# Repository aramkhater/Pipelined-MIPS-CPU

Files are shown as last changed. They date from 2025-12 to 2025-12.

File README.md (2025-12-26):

# Pipelined MIPS CPU 

## Overview

This project is a VHDL implementation of a **32-bit Pipelined MIPS CPU** architecture. It aims to create a high-performance processor that executes instructions through five pipeline stages—**IF, ID, EX, MEM, and WB**—to optimize instruction throughput. The system includes robust logic for **Forwarding** and **Data Hazard Detection** to handle dependencies and control flow changes in real hardware.

---

## Table of Contents

* [System Design](#system-design)
* [Control Unit](#control-unit)
* [Data Path & Pipeline Stages](#data-path--pipeline-stages)
* [Hazard Management](#hazard-management)
* [Verification & Performance](#verification--performance)

---

## System Design

The design encapsulates all necessary modules for pipelined MIPS operation, integrating memory components and specialized hazard units.

### File Descriptions

**`aux_package.vhd`**
* Defines all component declarations, enabling interconnections between the various stages and control modules.

**`MIPS.vhd`**
* Serves as the top-level structural model, integrating all pipeline stages and the hazard/forwarding units.
* **Inputs/Outputs:**
    * Reset and clock inputs, including PLL integration for hardware deployment.
    * `BPADDR_i` for hardware breakpoint support.
    * Performance counters: `mclk_cnt_o` (clock cycles), `inst_cnt_o` (instructions), and `STCNT_o` (stalls).

**`IFETCH.VHD`**
* Manages the Program Counter (PC) and retrieves instructions from the Instruction TCM (ITCM).
* Supports PC increments, branch targets, and jump addresses while allowing for pipeline stalls via `pc_write_i`.

**`IDECODE.VHD`**
* Implements the Register File consisting of 32 registers of 32-bit width.
* Decodes instructions, performs sign-extension, and handles branch condition evaluation at the ID stage to reduce branch penalties.

**`EXECUTE.VHDL`**
* Performs arithmetic and logical operations using the ALU.
* Handles operand selection from the Register File or forwarded data from MEM/WB stages.

**`DMEMORY.VHD`**
* Implements the Data TCM (DTCM) for load and store operations.
* Interfaces with the pipeline to read data for `lw` or write data for `sw` instructions.

**`WB.vhd`**
* The Write Back stage, which selects between the ALU result and memory data to be written back to the Register File.

---

## Control Unit

**`CONTROL.VHD`**
* Implements the main combinatorial control logic.
* Generates signals such as `RegWrite`, `MemtoReg`, `ALUSrc`, and `Branch` based on the 6-bit opcode and function code.
* Supports R-type, I-type (e.g., `addi`, `lw`), and J-type (e.g., `jmp`, `jal`, `jr`) instructions.

---

## Data Path & Pipeline Stages

The datapath is divided into registers that coordinate data flow between cycles:
* **`IF_ID.vhd`**: Captures fetched instructions and $PC+4$.
* **`ID_EX.vhd`**: Passes decoded register values, control signals, and immediates to the execution stage.
* **`EX_MEM.vhd`**: Carries ALU results and store data to the memory stage.
* **`MEM_WB.vhd`**: Routes memory data or ALU results to the final write-back logic.

---

## Hazard Management

This processor includes dedicated hardware to resolve dependencies that arise in pipelined architectures:

**`Forwarding_Unit.vhd`**
* Resolves data hazards by routing data directly from the EX/MEM or MEM/WB stages back to the ALU inputs.
* Improves performance by allowing the CPU to use a result before it is officially written to the Register File.

**`Datahazard_Unit.vhd`**
* Detects Load-Use hazards where an instruction requires data immediately after a `lw` instruction.
* Stalls the pipeline by disabling PC and IF/ID updates and inserting a "nope" (no-op) into control signals.
* Manages Control Hazards by flushing the pipeline (clearing IF/ID) when a branch or jump is taken.

---

## Verification & Performance

The system was verified through a comprehensive process:
* **ModelSim Simulation:** Functional correctness was tested using a Matrix Addition program. Waveforms verified correct forwarding, stall insertion on hazards, and flush behavior.
* **Hardware Validation:** The design was synthesized using Quartus and deployed on a DE10-Standard FPGA.
* **SignalTap Analysis:** Real-time execution was captured to confirm instruction flow and breakpoint triggers at address `0x030`.
* **Performance Results:** The Matrix Addition test achieved an **IPC of 0.83** with a restricted $F_{max}$ for the system clock of **32.79 MHz**.

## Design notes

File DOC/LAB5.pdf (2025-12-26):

## Pipelined MIPS CPU on FPGA – Design and

## Verification Report

## ADVANCED CPU ARCHITECTURE AND HARDWARE

## ACCELERATORS LAB

361.1.4693

## Ahseen Alazazma 324038132

## Aram Khater 314813452

### 1. LAB overview:

In this lab, we implemented a pipelined MIPS CPU architecture supporting full data

hazard detection and forwarding mechanisms. The design includes all five standard

pipeline stages — IF, ID, EX, MEM, and WB — with additional logic to handle stalls,

flushes, and control flow changes.

The CPU was first verified using ModelSim through the simulation of a custom hand-

written assembly program, ensuring functional correctness and proper pipeline behavior.

After successful simulation, the design was synthesized using Quartus and deployed on

an FPGA. Final validation was performed using SignalTap to capture and inspect live

execution, confirming correct memory access, instruction sequencing, and pipeline

control under real hardware conditions.

### 2. Test program

To evaluate the functionality of our MIPS CPU, we ran several test programs covering

arithmetic operations, memory access (load/store), branches, and jumps. One

representative example is a matrix addition program written in C and compiled to MIPS

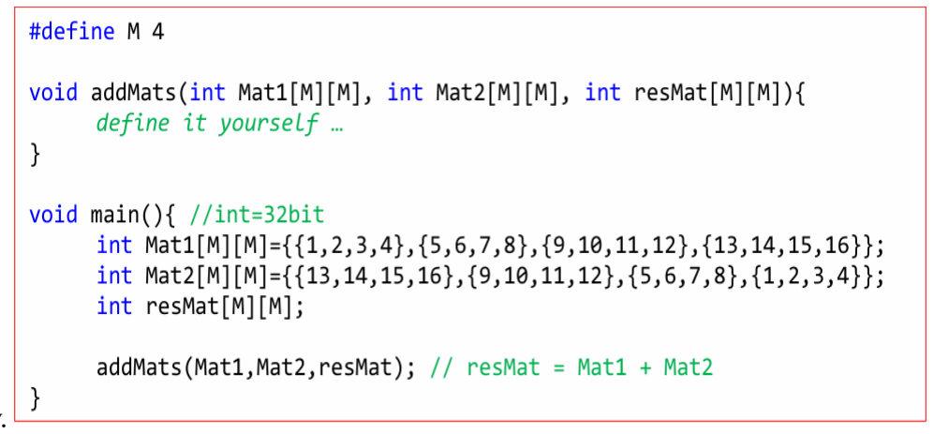
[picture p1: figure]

assembly.

Figure 1: C program for adding two matrices

And it’s version in assembly:

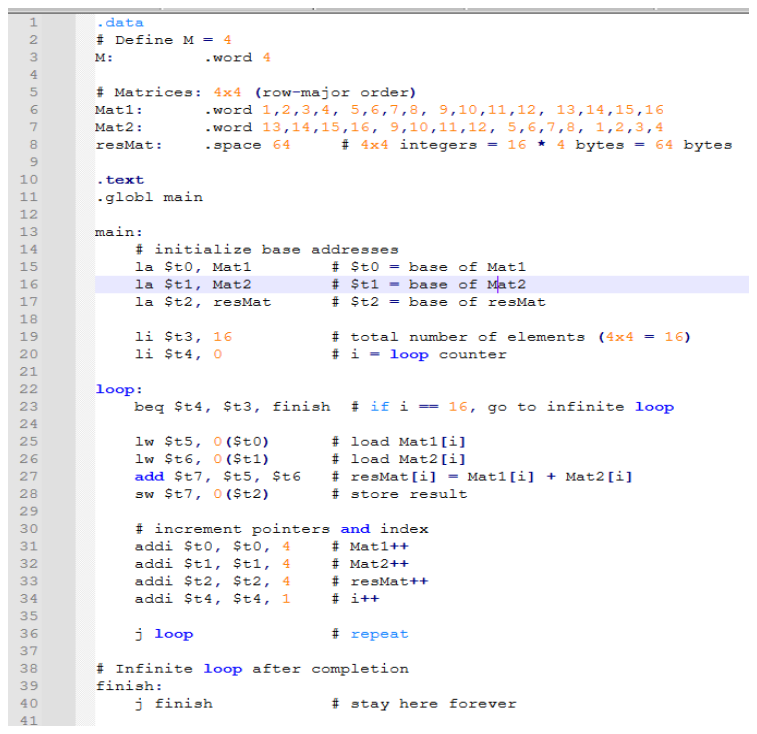
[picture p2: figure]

Figure 2: assembly program

### 3. Simulation Verification (ModelSim)

ModelSim simulation confirmed correct instruction sequencing and data propagation through the pipeline stages. We used waveform inspection to verify:

- Proper forwarding of values (e.g., add after lw)
- Correct stall insertion on load-use hazards
- Accurate memory writes at the correct cycle
- Instruction alignment across pipeline registers

The following show how the data flow in pipeline:

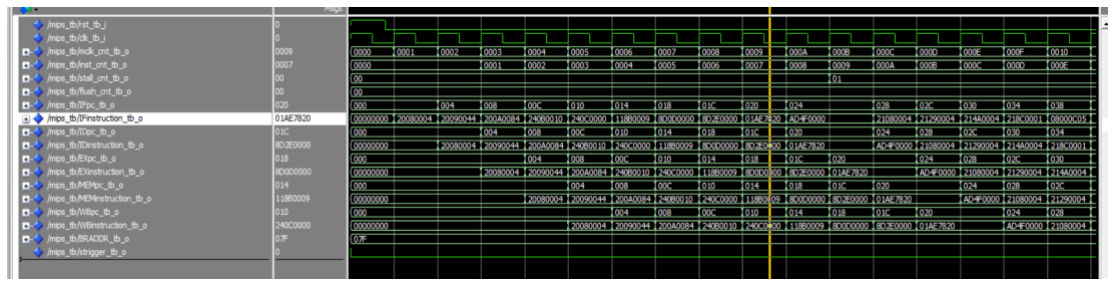
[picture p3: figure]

Figure 3: Pipeline flow

The following show correct handling when the branch taken the next fetched instruction is flushed and the flush counter increased by 1:

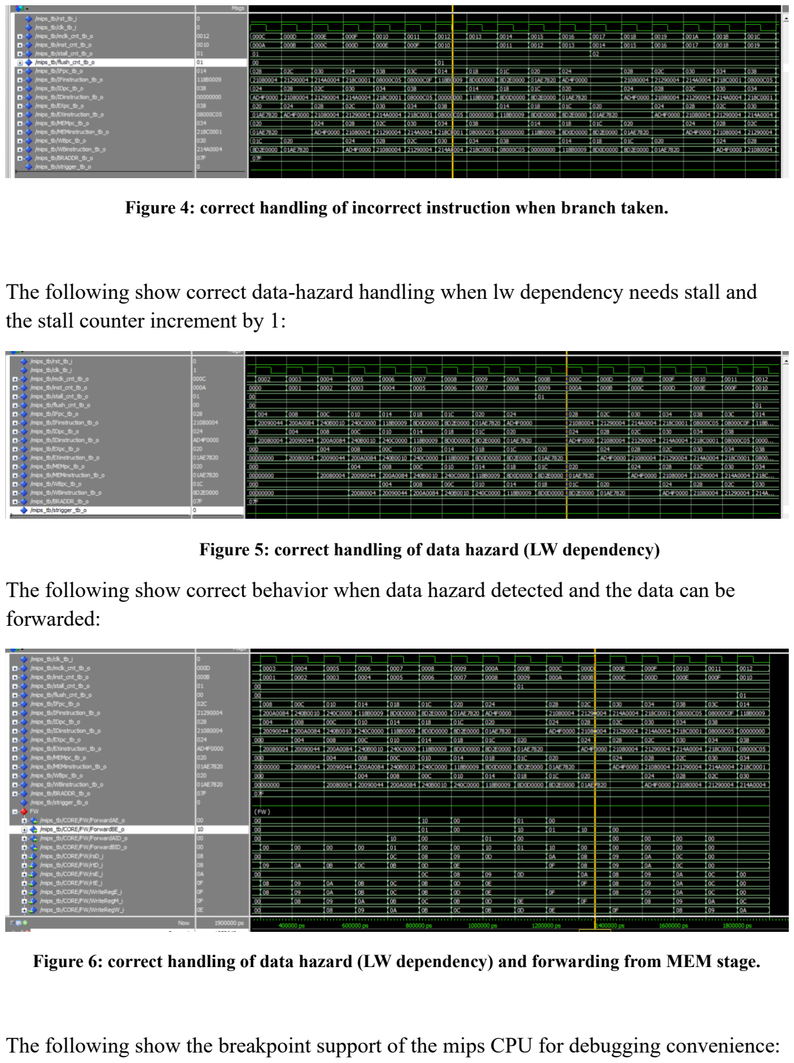
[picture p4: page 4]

Figure 4: correct handling of incorrect instruction when branch taken.

The following show correct data-hazard handling when lw dependency needs stall and the stall counter increment by 1:

Figure 5: correct handling of data hazard (LW dependency)

The following show correct behavior when data hazard detected and the data can be forwarded:

Figure 6: correct handling of data hazard (LW dependency) and forwarding from MEM stage.

The following show the breakpoint support of the mips CPU for debugging convenience:

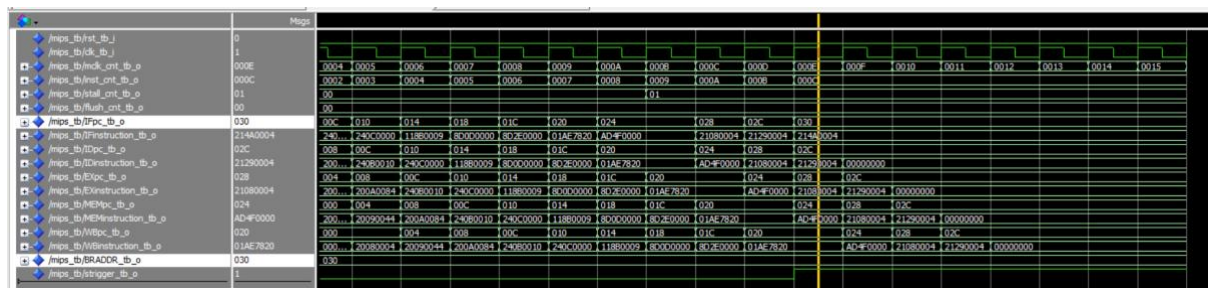
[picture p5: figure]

Figure 7: breakpoint support

The following show the content data memory after completing the program, which match the theoretical behavior:

Figure 8: Data memory content (the matrices and the summed matrix)

### 4. Hardware Validation (Quartus + SignalTap)

After ModelSim verification, the CPU was synthesized and deployed on the FPGA.

Using SignalTap, we validated:

- Live instruction flow across pipeline stages
- Real-time stalls and flushes
- Breakpoint detection
- Output memory content

The contents of memory after execution were compared between Quartus and ModelSim and matched, confirming consistent behavior between simulation and hardware.

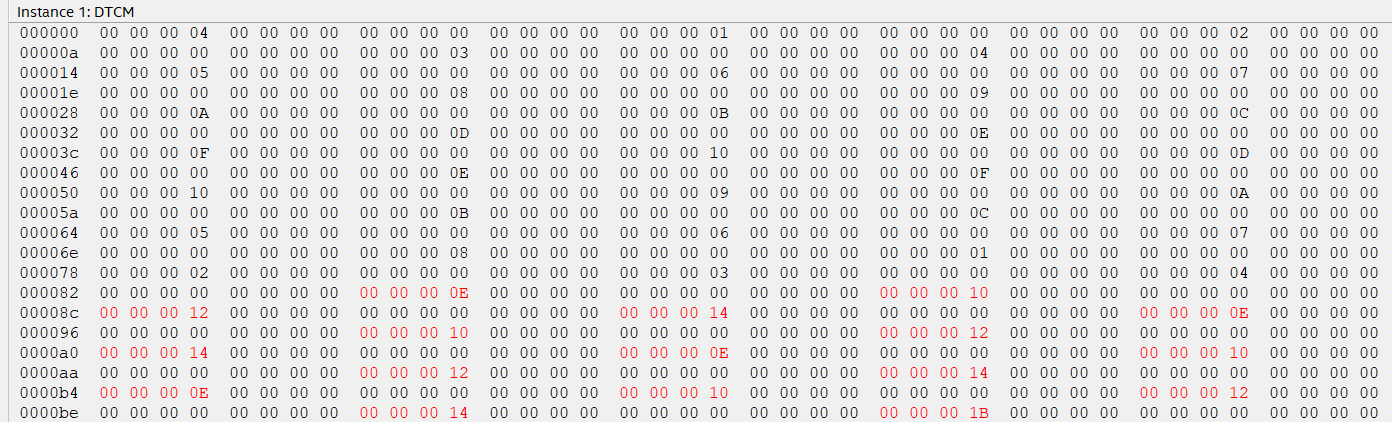
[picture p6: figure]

Figure 9: Quartus memory content

To validate runtime control, a breakpoint mechanism was implemented. Figure 9 shows a capture in SignalTap where execution halts when the PC reaches address 0x030, as expected.

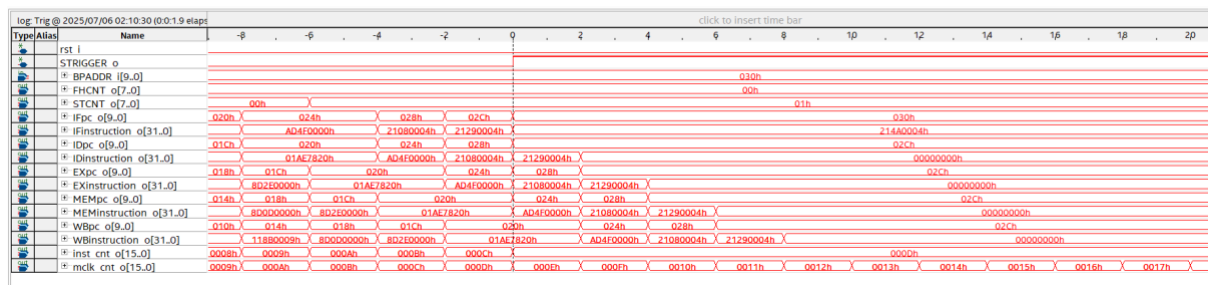
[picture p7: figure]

Figure 10: SignalTap breakpoint at PC=0x30

This confirms correct operation of the breakpoint detection and integration with pipeline control.

The following show correct stalling after data hazard detected and stall counter incremented by 1:

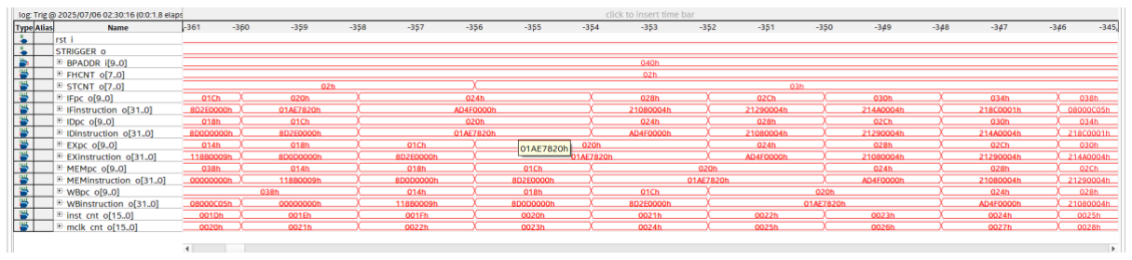
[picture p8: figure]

Figure 11: SignalTap, stall after data dependency.

The following show correct stalling after wrong instruction detected (branch taken) and flush counter incremented by 1:

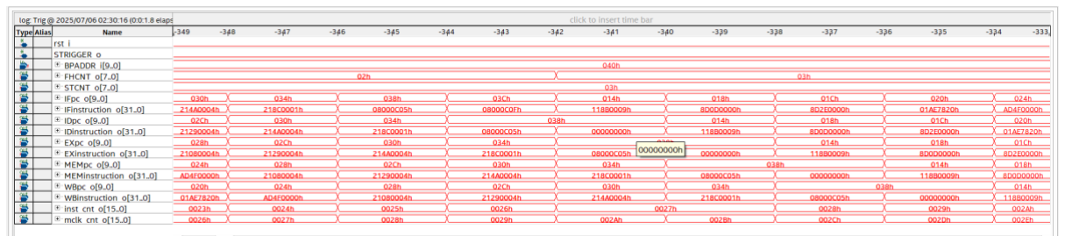
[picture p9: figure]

Figure 12: SignalTap, flush after branch taken.

### 5. Comparison

As shown in Figures X and Y, the data memory after execution is consistent between simulation (ModelSim) and real hardware (Quartus). This validates that memory control logic, address calculation, and write-back stages behave identically.

### 6. IPC calculation

The execution of the program took 199 clock cycle, 181 instructions, 16 stalls and 16 flush.

We can calculate the IPC using the following equation:

Using the clock cycle counter and instruction counter on FPGA, we calculated the IPC (Instructions Per Cycle) of the matrix addition program to be approximately 0.83. This accounts for stalls due to load-use hazards and control flow changes like branches.

### 7. critical path and maximum clock for pipelined mips

Following the maximum clock speed for the pipelined mips:

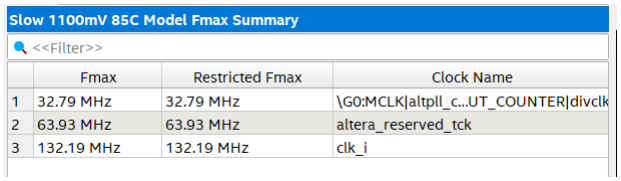
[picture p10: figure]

Figure 13: Maximum clock speed of the pipelined mips

The following show the critical path of the pipelined mips CPU:

Figure 14: critical path of the pipelined mips.

### 8. critical path and maximum clock for pipeline mips

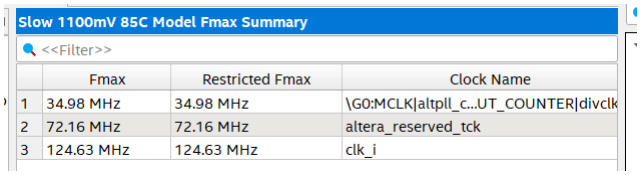
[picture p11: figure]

Figure 15: Maximum clock speed of the single cycle mips.

Figure 16: critical path of the single cycle mips.

### 9. RTL

MIPS Pipeline Processor RTL

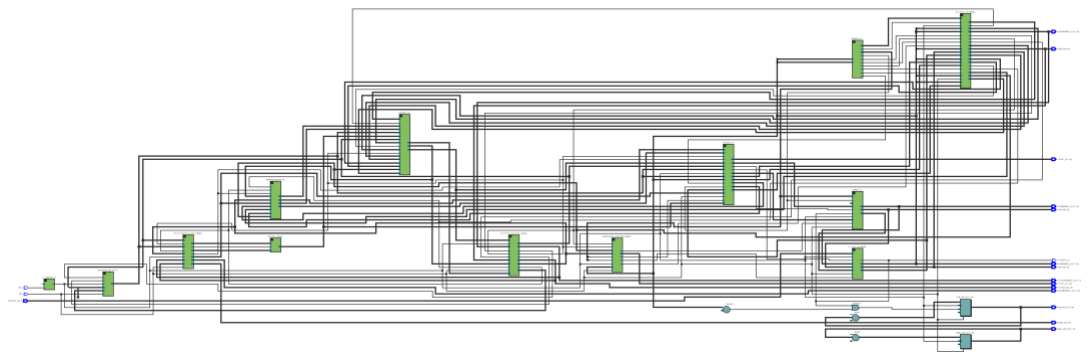
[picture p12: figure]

Instruction Fetch

Instruction Fetch (IF) stage is responsible for retrieving the next instruction to be executed. It reads the current value of the Program Counter (PC), uses it to access the instruction memory, fetches the instruction located at that address, and calculates the address of the next instruction by adding 4 to the PC. The fetched instruction and the incremented PC (PC + 4) are then passed to the next pipeline stage (Instruction Decode), while the PC is updated to point to the next instruction, unless a branch or jump alters the flow.

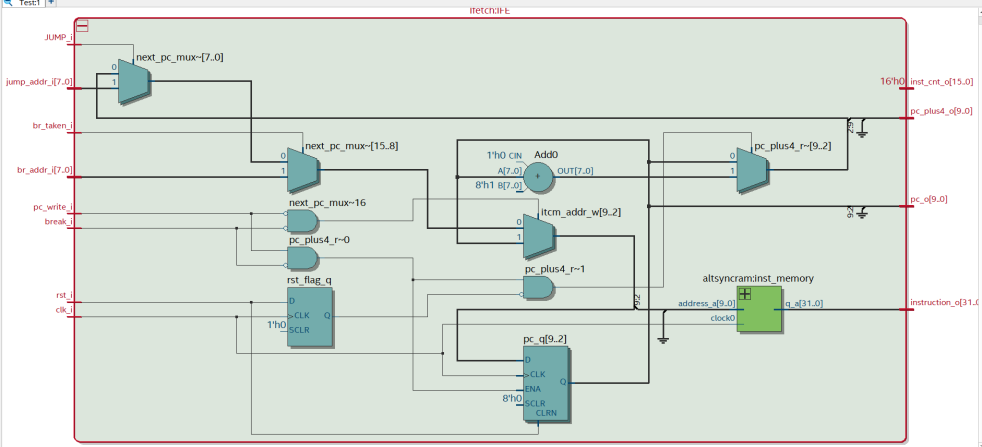
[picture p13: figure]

Instruction Decode

Instruction Decode (ID) stage interprets the fetched instruction and prepares necessary data for execution. It decodes the instruction to determine the operation type and identifies the source and destination registers. The processor reads the values of the source registers from the register file, and sign-extends the immediate field if the instruction requires it (e.g., for load/store or arithmetic immediate operations). Additionally, the ID stage calculates potential branch targets and checks branch conditions. All decoded information and register values are passed to the Execute (EX) stage via the ID/EX pipeline register.

Control Unit

Control Unit is responsible for generating the appropriate control signals based on the decoded instruction. During the Instruction Decode (ID) stage, the Control Unit examines the opcode (and function code for R-type instructions) to determine the type of instruction (e.g., arithmetic, memory access, or branch) and produces signals that guide the operation of each pipeline stage. These signals control actions like register writing, ALU operations, memory reading/writing, and branching. The Control Unit ensures that each component in the datapath performs the correct function for the given instruction, enabling coordinated and correct execution.

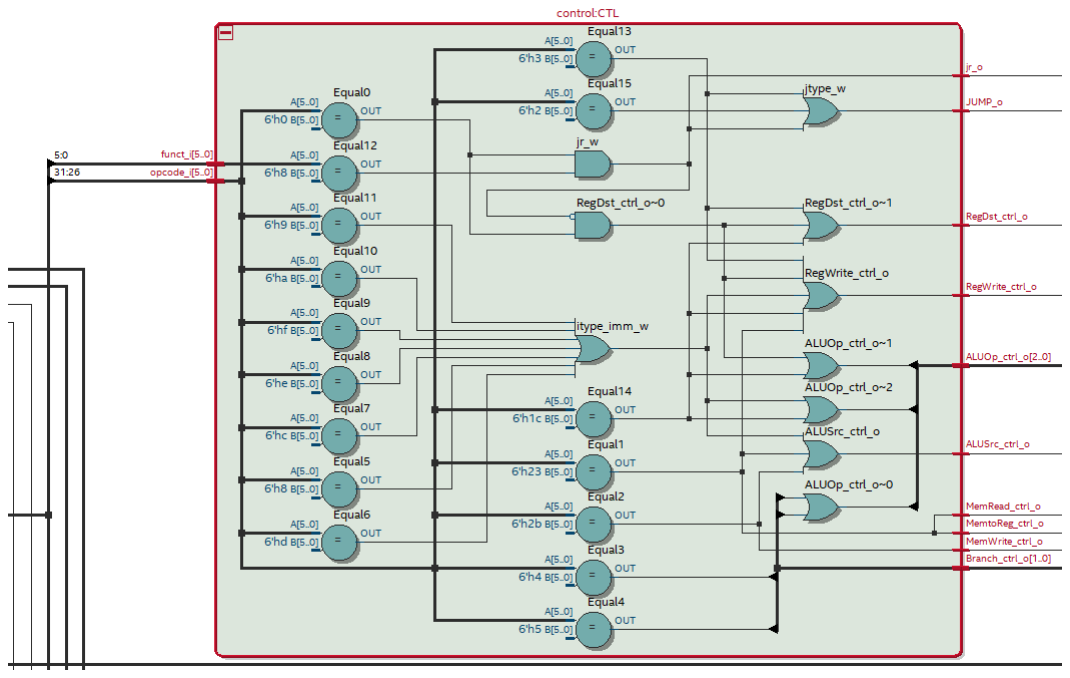
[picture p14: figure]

Forwarding Unit

The Forwarding Unit in a MIPS pipeline processor is a hazard detection mechanism that resolves data hazards by forwarding data directly between pipeline stages without waiting for it to be written back to the register file. When an instruction depends on the result of a previous instruction that has not yet completed the Write Back (WB) stage, the Forwarding Unit detects this and routes the needed data from the EX or MEM stage back to the EX stage inputs. This allows instructions to execute without stalling the pipeline, improving performance and maintaining correct program behavior.

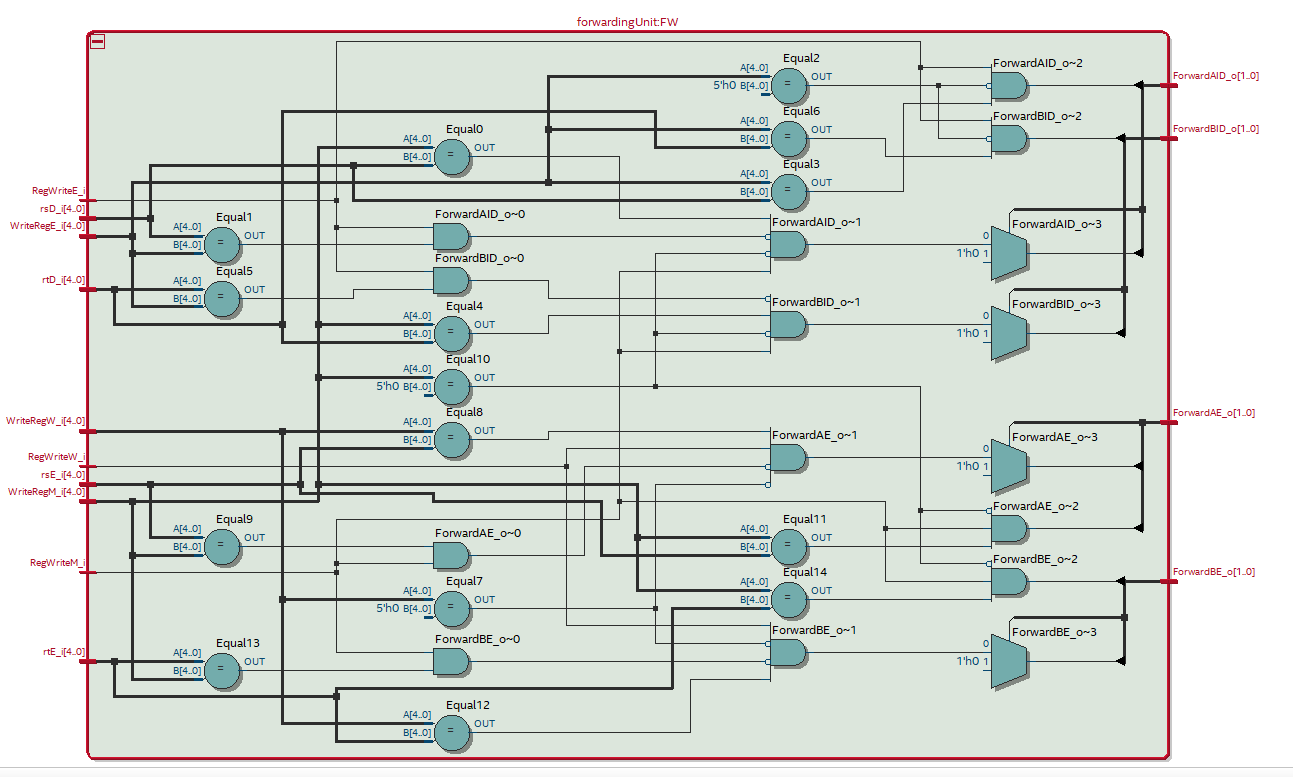
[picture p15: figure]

Hazard Unit

The Hazard Detection Unit in a MIPS pipeline processor is responsible for identifying situations that could cause incorrect execution due to data or control hazards, and applying solutions like stalls (pausing pipeline stages) or flushes (clearing incorrect instructions).

- It stalls the pipeline (usually by preventing updates to the PC and IF/ID registers) when a load-use data hazard is detected — for example, when an instruction tries to use a register immediately after a lw that loads it.
- It flushes instructions (inserting no-ops) when a control hazard occurs, such as after a taken branch or jump, to discard instructions that were fetched based on the wrong PC.

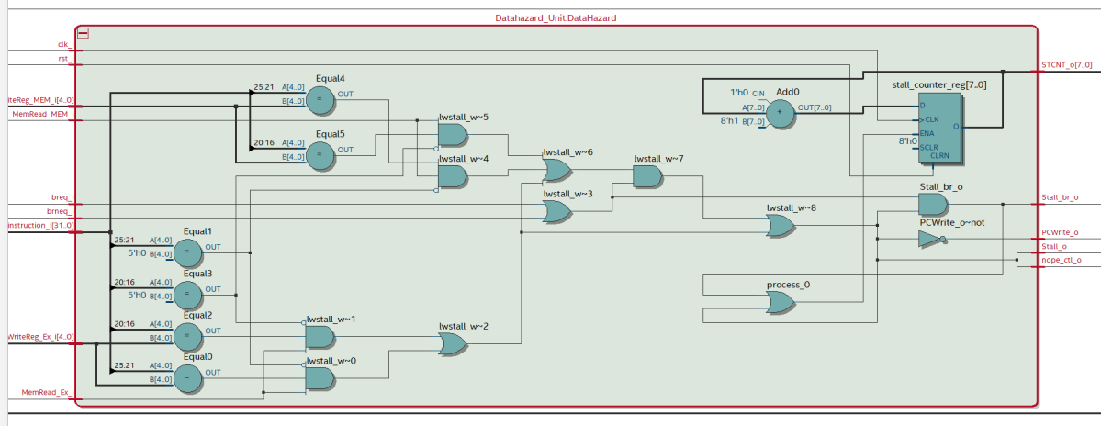
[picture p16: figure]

Execute Stage

The Execute (EX) stage in a MIPS pipeline processor performs the core computation or address calculation for the instruction. For arithmetic or logic instructions, the ALU carries out the operation (e.g., add, sub, and). For memory instructions like lw or sw, it calculates the effective memory address by adding the base register and the offset. This stage also uses forwarded data if needed and selects the correct ALU operands based on control signals. The results are then passed to the Memory (MEM) stage.

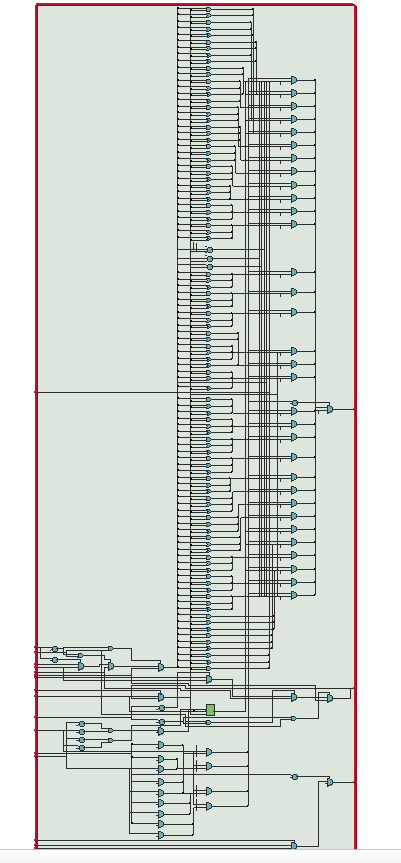
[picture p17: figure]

Data Memory

The Memory (MEM) stage in a MIPS pipeline processor handles data memory access for load and store instructions. If the instruction is a load (e.g., lw), it uses the address calculated in the EX stage to read data from memory. If it’s a store (e.g., sw), it writes data from a register to the calculated memory address. For other instruction types (like arithmetic or branches), this stage typically just passes the result forward without accessing memory. The output of this stage is then forwarded to the Write Back (WB) stage.

Write Back Stage

The Write Back (WB) stage is the final stage, where the result of an instruction is written back to the register file. For R-type and I-type arithmetic instructions, the ALU result is written to the destination register. For load instructions (e.g., lw), the data read from memory is written to the target register. The control unit determines which value is written and to which register, based on the instruction type.

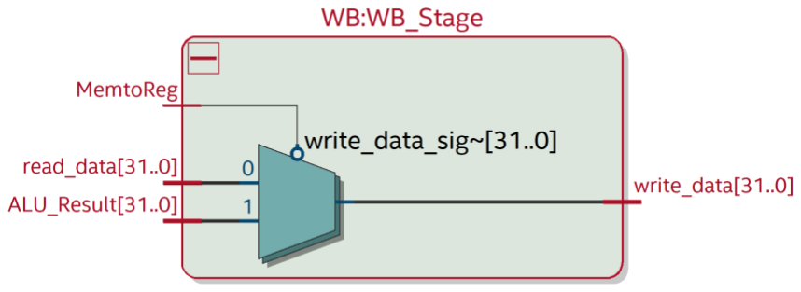
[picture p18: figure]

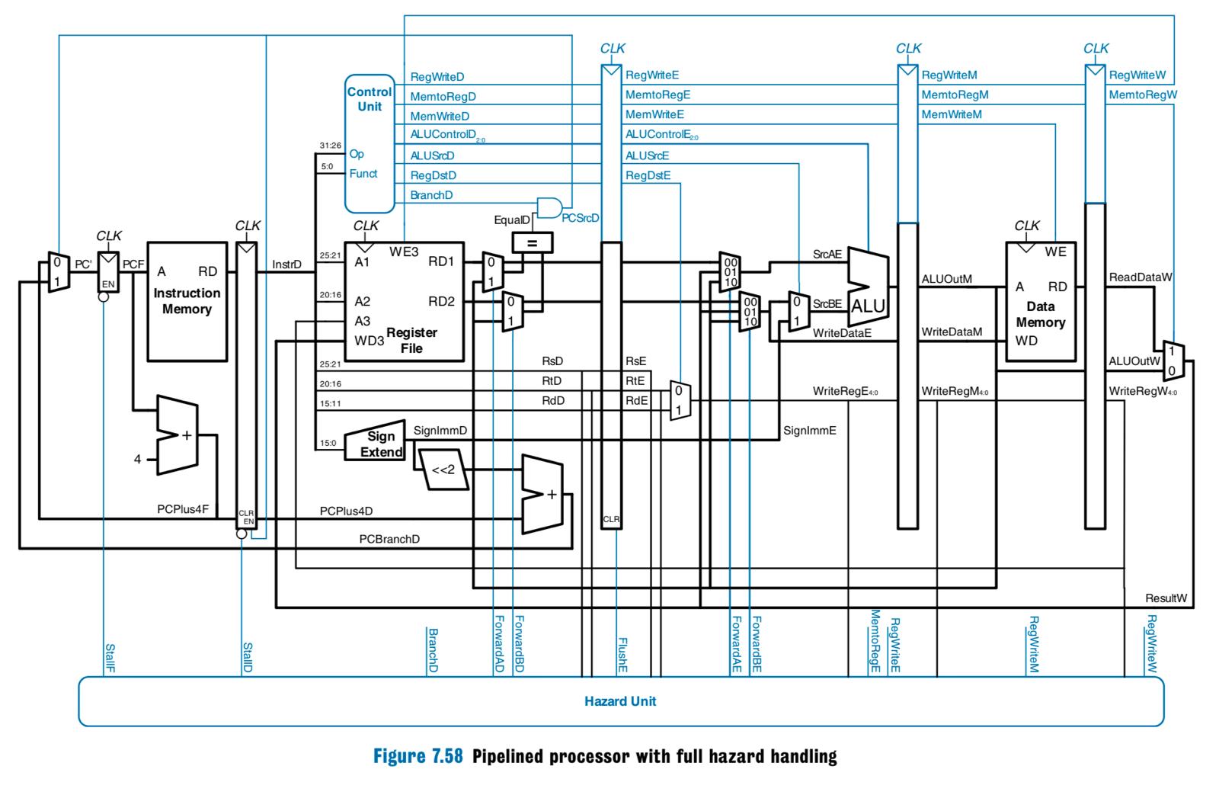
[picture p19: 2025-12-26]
DOC/mips_architecture.jpg

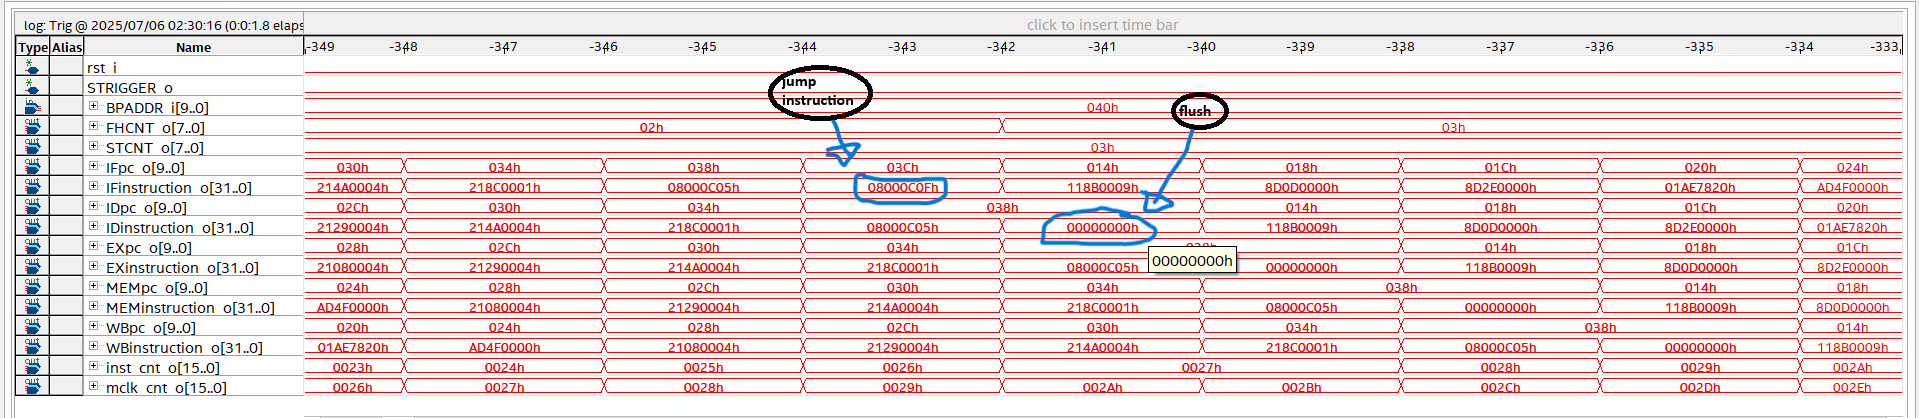
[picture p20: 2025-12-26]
DOC/flush.png

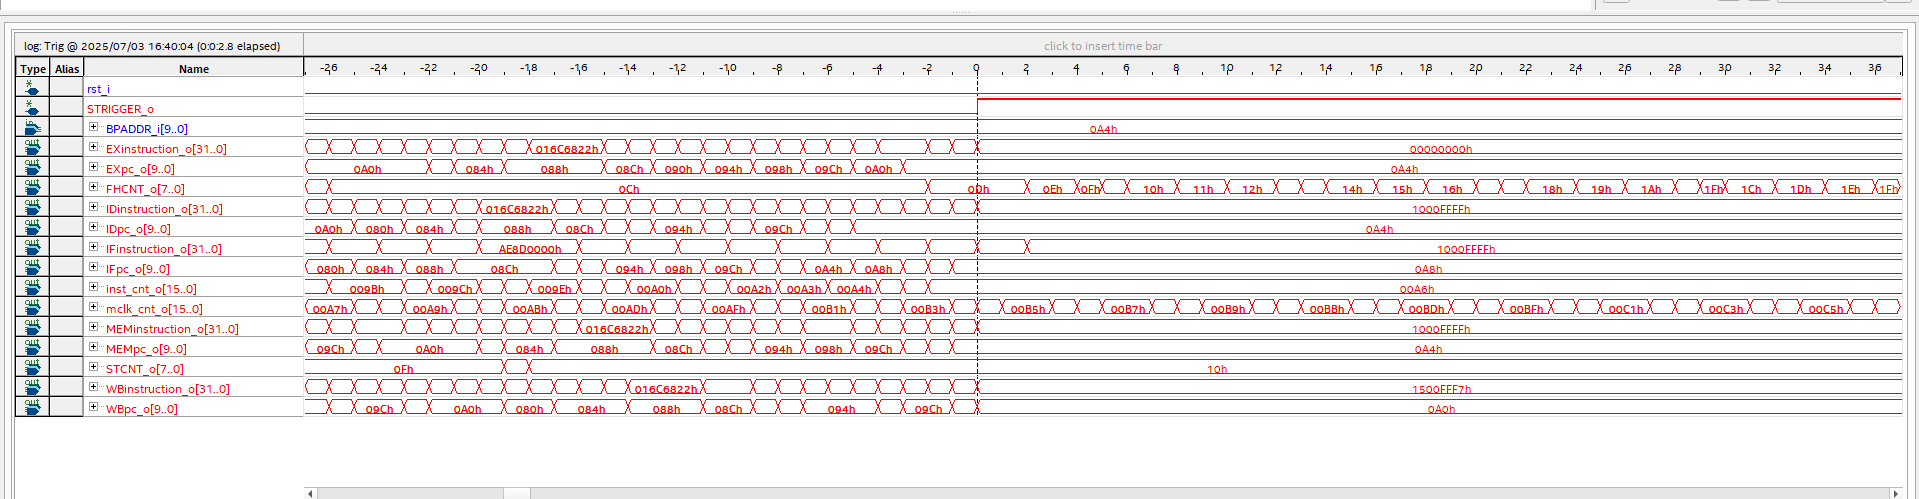
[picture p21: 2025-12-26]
DOC/ipc_counters.png

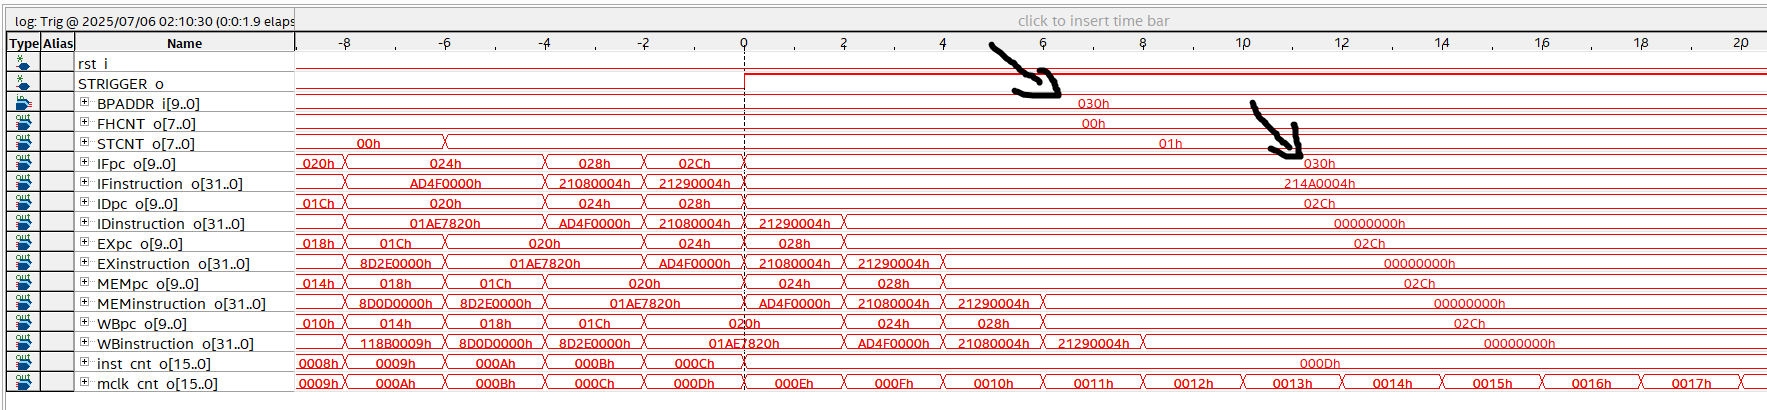
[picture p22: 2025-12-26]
DOC/breakpoint.png

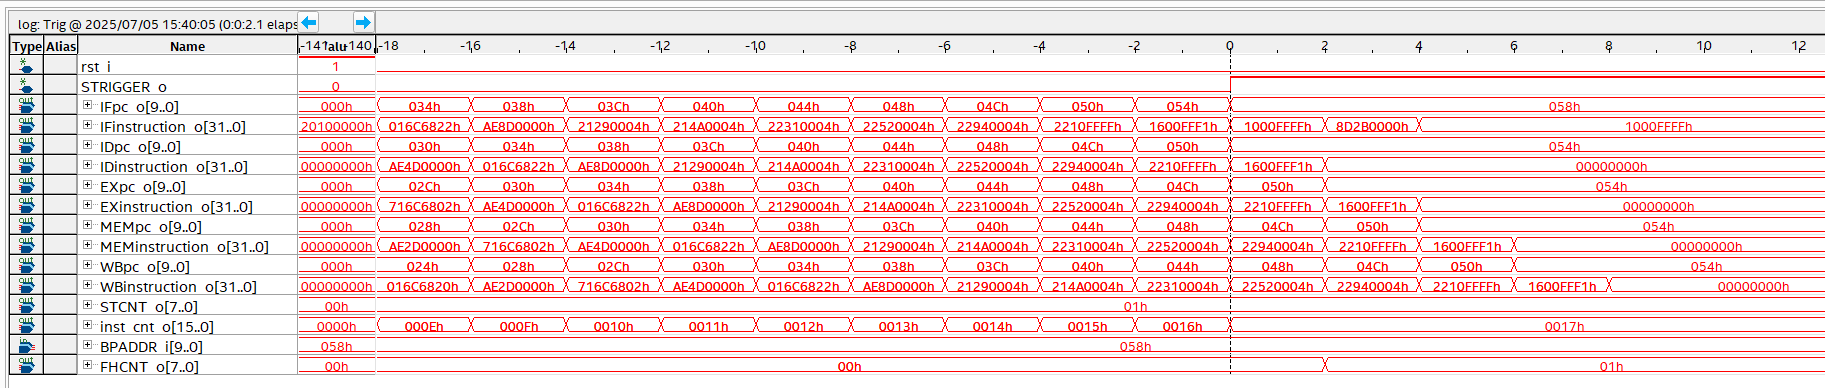
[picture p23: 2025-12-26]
DOC/pipeline_flow.png

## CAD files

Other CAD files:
Quartus/stp.stp

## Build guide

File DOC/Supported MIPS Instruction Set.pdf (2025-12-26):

### Support of MIPS Assembly Instruction Set

Legend: Supported instructions - blue, Unsupported instructions (to be implemented as part of LAB5) - black

Arithmetic Instructions
Instruction | Example | Meaning | Comments
add | add $1,$2,$3 | $1=$2+$3
subtract | sub $1,$2,$3 | $1=$2-$3
add immediate | addi $1,$2,100 | $1=$2+100
Multiply (without overflow) | mul $1,$2,$3 | $1=$2*$3 | The destination register is only 32 bits, where for the two source registers, only the lower half word (16-bit) content matters

Logical and shift Instructions
Instruction | Example | Meaning | Comments
and | and $1,$2,$3 | $1=$2&$3 | Bitwise AND
or | or $1,$2,$3 | $1=$2|$3 | Bitwise OR
xor | xor $1,$2,$3 | $1=$2^$3 | Bitwise XOR
and immediate | andi $1,$2,100 | $1=$2&100 | Bitwise AND with immediate value
or immediate | ori $1,$2,100 | $1=$2|100 | Bitwise OR with immediate value
xor immediate | xori $1,$2,100 | $1=$2^100 | Bitwise XOR with immediate value
shift left logical | sll $1,$2,10 | $1=$2<<10 | Shift left by a constant number of bits
shift right logical | srl $1,$2,10 | $1=$2>>10 | Shift right by a constant number of bits

Data Transfer Instructions
Instruction | Example | Meaning | Comments
move | move $1,$2 | $1=$2 | Pseudo-instruction (provided by MARS Assembler, not processor!) Copy from register to register.
load address | la $1, label | $1= label address | Pseudo-instruction (provided by MARS Assembler, not processor!) Loads the computed address of a label (not its data content) into a register
load immediate | li $1,100 | $1=100 | Pseudo-instruction (provided by MARS Assembler, not processor!) Loads an immediate value into a register
load word | lw $1,100($2) | $1=Memory[$2+100]
store word | sw $1,100($2) | Memory[$2+100]=$1
load upper immediate | lui $1,100 | $1=100x2¹⁶ | Load constant into upper 16 bits. Lower 16 bits are set to zero.

Conditional Branch Instructions
Instruction | Example | Meaning | Comments
branch on equal | beq $1,$2,100 | if($1==$2) go to PC+4+100 | Test if registers are equal
branch on not equal | bne $1,$2,100 | if($1!=$2) go to PC+4+100 | Test if registers are not equal
branch on greater or equal than | bge $1,$2,100 | if($1>=$2) go to PC+4+100 | Pseduo-instruction
branch on less than | blt $1,$2,100 | if($1<$2) go to PC+4+100 | Pseduo-instruction

Comparison Instructions
Instruction | Example | Meaning | Comments
set on less than | slt $1,$2,$3 | if($2<$3)$1=1; else $1=0 | Test if less than. If true, set $1 to 1. Otherwise, set $1 to 0.
set on less than immediate | Slti $1,$2,100 | if($2<100)$1=1; else $1=0 | Test if less than. If true, set $1 to 1. Otherwise, set $1 to 0.

Unconditional Jump Instructions
Instruction | Example | Meaning | Comments
jump | j 1000 | go to address 1000 | Jump to target address
jump register | jr $ra | go to return address stored in $ra | For switch, procedure return
jump and link | jal 1000 | 1. Save the procedure return address $ra=PC+4 2. Go to a procedure call address, which starts at address 1000 | Use when making procedure call. This saves the return address in $ra

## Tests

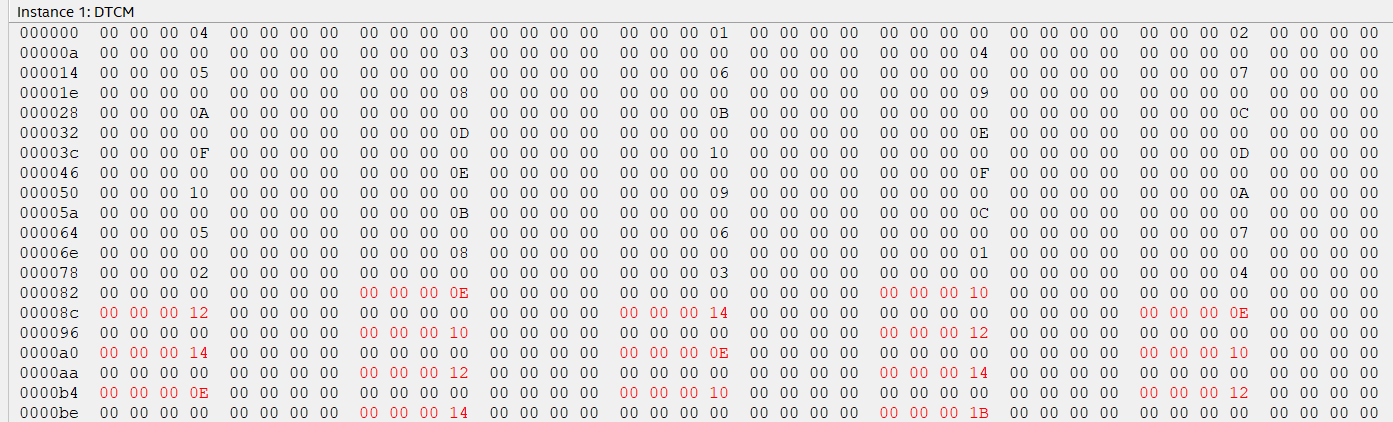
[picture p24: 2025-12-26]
DOC/memorey_validation.png

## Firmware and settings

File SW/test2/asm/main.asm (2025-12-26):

.data

arr1: .word  1 ,2 ,3 ,4 ,5 ,6 ,7 ,8 ,   
arr2: .word  100,99,98,97,96,95,94,93,	      
res1: .space 32  # SIZE*4=32[Byte] - ADD result array
res2: .space 32  # SIZE*4=32[Byte] - SUB result array
res3: .space 32  # SIZE*4=32[Byte] - MUL result array
SIZE: .word  8


.text
.globl main

main:
	li $sp,0x01FC		# stack initial address is 200
	lw $s0,SIZE($0)		# s0 = SIZE	
	la $t1,arr1   		# t1 points to arr1
	la $t2,arr2		# t2 points to arr2
	la $s1,res1		# s1 points to res1
	la $s2,res2		# s2 points to res2
	la $s3,res3		# s3 points to res3
loop:
	addi $sp,$sp,-16
	sw   $s0,12($sp)	# push SIZE
	sw   $s1,8($sp)		# push res1 pointer
	sw   $t2,4($sp)		# push arr2 pointer
	sw   $t1,0($sp)		# push arr1 pointer
	jal  mat_add
	
	addi $sp,$sp,-16
	sw   $s0,12($sp)	# push SIZE
	sw   $s2,8($sp)		# push res2 pointer
	sw   $t2,4($sp)		# push arr2 pointer
	sw   $t1,0($sp)		# push arr1 pointer
	jal  mat_sub
	
	addi $sp,$sp,-16
	sw   $s0,12($sp)	# push SIZE
	sw   $s3,8($sp)		# push res3 pointer
	sw   $t2,4($sp)		# push arr2 pointer
	sw   $t1,0($sp)		# push arr1 pointer
	jal  mat_mul
	
finish:	beq $zero,$zero,finish

	
